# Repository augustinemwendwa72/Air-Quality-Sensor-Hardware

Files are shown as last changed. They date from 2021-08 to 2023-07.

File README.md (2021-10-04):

# sensors.AFRICA GSM AQ Kits Hardware

## Tools used

* Autodesk Eagle

* Fusion360

## sensors.AFRICA Stack

1. Firmware - https://github.com/CodeForAfrica/sensors.AFRICA-AQ-sensors-software
2. API - https://github.com/CodeForAfricaLabs/sensors.AFRICA-AQ-api
3. Map - https://github.com/CodeForAfrica/sensors.AFRICA-AQ-map-v2

## Documentation

The Documentation is under development.

## License

GNU General Public License v3.0

sensors.AFRICA is a citizen-science focused project by Code for Africa that seeks to address data gaps by providing low cost sensors, which people can use to measure and monitor the quality of the air, water, and environment in their communities. This web app seeks to be the public portal through which most users would discover and explore the data and intiative.

Copyright (C) 2021 Code for Africa

This program is free software: you can redistribute it and/or modify
it under the terms of the GNU General Public License as published by
the Free Software Foundation, either version 3 of the License, or
(at your option) any later version.

This program is distributed in the hope that it will be useful,
but WITHOUT ANY WARRANTY; without even the implied warranty of
MERCHANTABILITY or FITNESS FOR A PARTICULAR PURPOSE. See the
GNU General Public License for more details.

You should have received a copy of the GNU General Public License
along with this program. If not, see <https://www.gnu.org/licenses/>

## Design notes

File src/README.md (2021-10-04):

# sensors.AFRICA / GSM AQ sensors hardware

This folder contains the Eagle design files for the sensors.AFRICA GSM boards.

### Folders

* **AQ_sensor** The Printed Circuit Board of the AQ kit

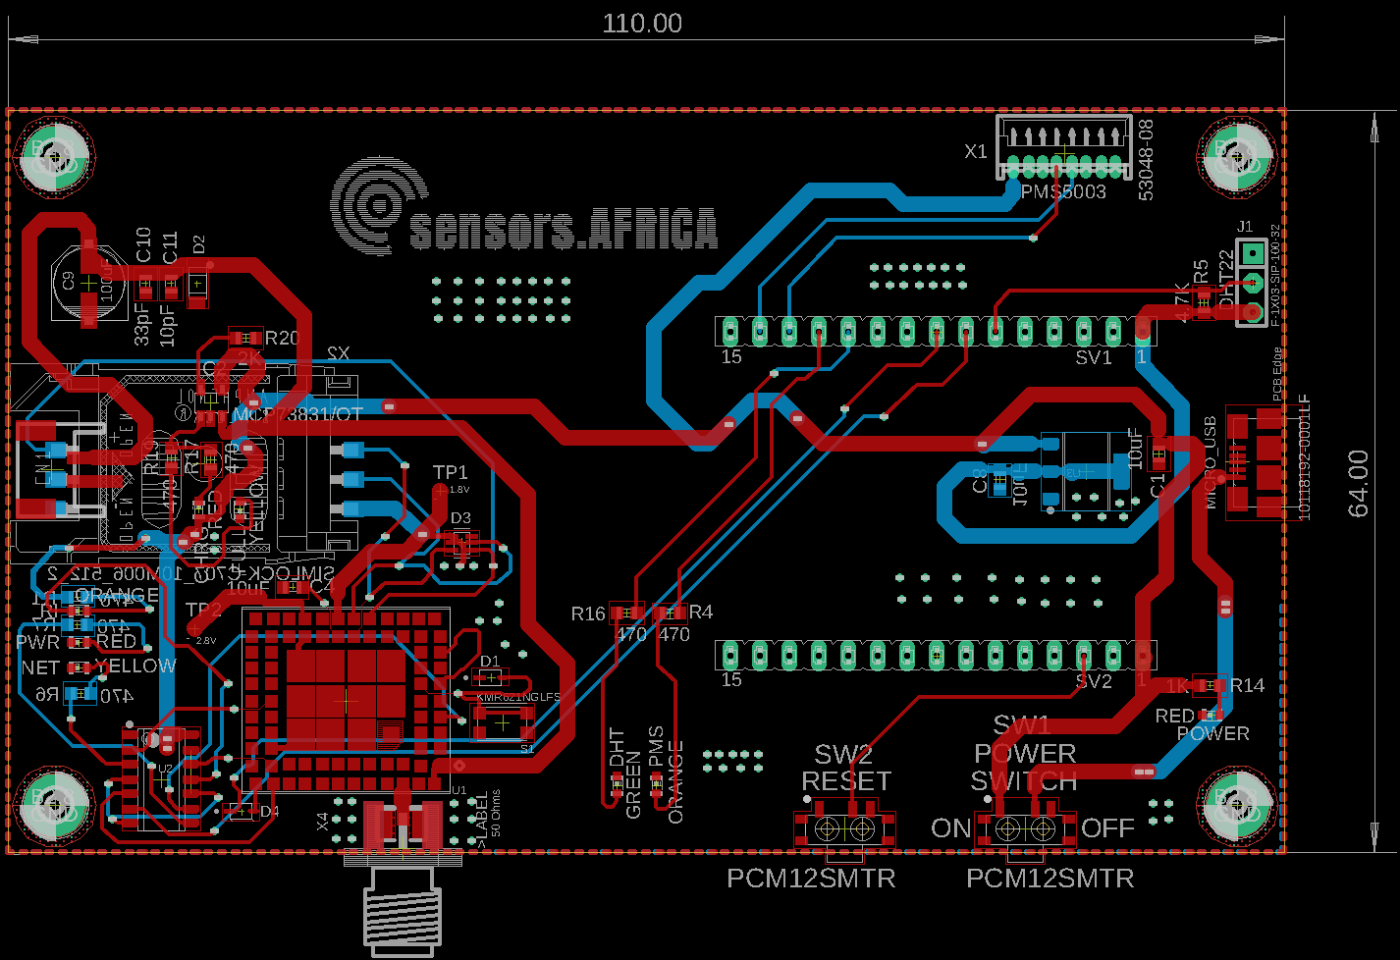
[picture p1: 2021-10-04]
src/AQ_sensors_GSM_brd.png

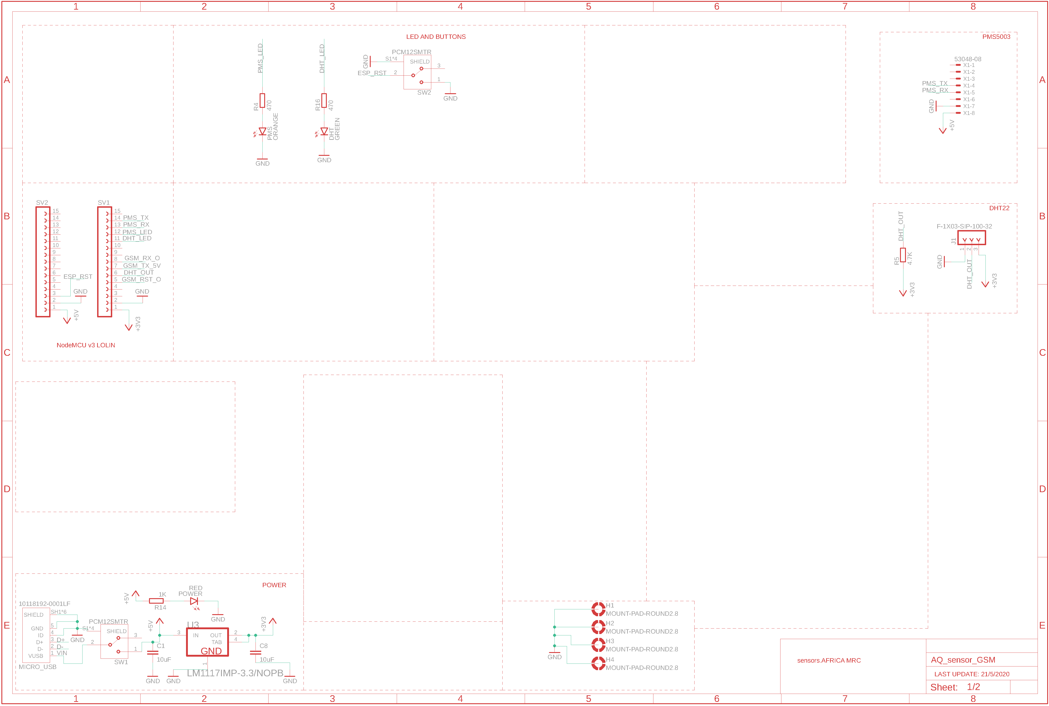
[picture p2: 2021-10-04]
src/AQ_sensors_GSM_sch.png

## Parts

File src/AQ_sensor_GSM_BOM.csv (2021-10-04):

Part | Value | Device | Package | Description | AVAILABILITY | BITS | CENTROID_NOT_SPECIFIED | CIIVA_IDS | CODE__IPC | CODE__JEDEC | CODE__JEITA | COMPONENT_LINK_1_DESCRIPTION | COMPONENT_LINK_1_URL | COMPONENT_LINK_3_DESCRIPTION | COMPONENT_LINK_3_URL | COMP_TYPE | DATASHEET | DATASHEET_VERSION | DESCRIPTION | DIGIKEY_DESCRIPTION | DIGIKEY_PART_NUMBER | FOOTPRINT_VARIANT_NAME_0 | FOOTPRINT_VARIANT_NAME_1 | FOOTPRINT_VARIANT_NAME_2 | F__NOM_VOLTAGEMAXMHZ | HIGH__RELIABILITY | ICC__NOM_VOLTAGEMAXMA | IMPORTED | IMPORTED_FROM | IMPORT_TS | INPUT_TYPE | IPC_LAND_PATTERN_NAME | JUNCTION_CAPACITANCE | LEAD_FREE | MANUFACTURER_PRODUCT_PAGE | MF | MFG_PACKAGE_IDENT | MFG_PACKAGE_IDENT_REV | MOUNTING_TECHNOLOGY | MOUSER_DESCRIPTION | MOUSER_PART_NUMBER | MP | MPN | OC_FARNELL | OC_NEWARK | OPERATING_TEMPERATURE_RANGEC | OUTPUT_TYPE | PACKAGE | PACKAGE_DESCRIPTION | PACKAGE_TOP_MARKING | PACKAGE_VERSION | PACKING | PIN_0_0_0_OUTSIDE_EDGE | PIN_0_1_0_OUTSIDE_EDGE | PIN_0_2_0_OUTSIDE_EDGE | PIN_0_3_2_OUTSIDE_EDGE | PIN_COUNT | POPULARITY | POWER_WISE
C1 | 10uF | C-EUC0603 | C0603 | CAPACITOR, European symbol |  |  |  |  |  |  |  |  |  |  |  |  |  |  |  |  |  |  |  |  |  |  |  |  |  |  |  |  |  |  |  |  |  |  |  |  |  |  |  |  |  |  |  |  |  |  |  |  |  |  |  |  |  | 73
C4 | 10uF | C-EUC0603 | C0603 | CAPACITOR, European symbol |  |  |  |  |  |  |  |  |  |  |  |  |  |  |  |  |  |  |  |  |  |  |  |  |  |  |  |  |  |  |  |  |  |  |  |  |  |  |  |  |  |  |  |  |  |  |  |  |  |  |  |  |  | 73
C8 | 10uF | C-EUC0603 | C0603 | CAPACITOR, European symbol |  |  |  |  |  |  |  |  |  |  |  |  |  |  |  |  |  |  |  |  |  |  |  |  |  |  |  |  |  |  |  |  |  |  |  |  |  |  |  |  |  |  |  |  |  |  |  |  |  |  |  |  |  | 73
C9 | 100uF | CPOL-EUD | PANASONIC_D | POLARIZED CAPACITOR, European symbol |  |  |  |  |  |  |  |  |  |  |  |  |  |  |  |  |  |  |  |  |  |  |  |  |  |  |  |  |  |  |  |  |  |  |  |  |  |  |  |  |  |  |  |  |  |  |  |  |  |  |  |  |  | 16
C10 | 33pF | C-EUC0603 | C0603 | CAPACITOR, European symbol |  |  |  |  |  |  |  |  |  |  |  |  |  |  |  |  |  |  |  |  |  |  |  |  |  |  |  |  |  |  |  |  |  |  |  |  |  |  |  |  |  |  |  |  |  |  |  |  |  |  |  |  |  | 73
C11 | 10pF | C-EUC0603 | C0603 | CAPACITOR, European symbol |  |  |  |  |  |  |  |  |  |  |  |  |  |  |  |  |  |  |  |  |  |  |  |  |  |  |  |  |  |  |  |  |  |  |  |  |  |  |  |  |  |  |  |  |  |  |  |  |  |  |  |  |  | 73
CHRG | RED | LEDCHIP-LED0603 | CHIP-LED0603 | LED |  |  |  |  |  |  |  |  |  |  |  |  |  |  |  |  |  |  |  |  |  |  |  |  |  |  |  |  |  |  |  |  |  |  |  |  |  |  |  |  |  |  |  |  |  |  |  |  |  |  |  |  |  | 26
CN1 |  | JST_2PIN-SMT-RA | JST-PH-2-SMT-RA | JST 2-Pin Connectors of various flavors
D1 | ON_SEMI_1N4148WSON_SEMI_1N4148WS_0_0 | ON_SEMI_1N4148WSON_SEMI_1N4148WS_0_0 | ON_SEMI_1N4148WS_0 | Small Signal Diodes |  |  | No |  |  |  |  |  |  |  |  |  | https://www.fairchildsemi.com/datasheets/1N/1N4148WS.pdf |  |  | DIODE GEN PURP 75V 150MA SOD323F | 1N4148WSFSCT-ND |  |  |  |  |  |  |  |  |  |  | SOD250125X70-2 |  | yes |  | ON Semi | CASE 477AB |  |  | Diodes - General Purpose, Power, Switching Small Signal Diode | 512-1N4148WS |  | 1N4148WS |  |  |  |  | SOD-323FL
D2 | ON_SEMICONDUCTOR_MMSZ5231BT1GON_SEMICONDUCTOR_MMSZ5231BT1G_0_0 | ON_SEMICONDUCTOR_MMSZ5231BT1GON_SEMICONDUCTOR_MMSZ5231BT1G_0_0 | ON_SEMICONDUCTOR_MMSZ5231BT1G_0 | ONSC-K1A2-2 |  |  |  | 804101 |  |  |  | Manufacturer URL | http://www.onsemi.com/ | Package Specification | http://www.onsemi.com/pub_link/Collateral/425-04.PDF |  | http://www.onsemi.com/pub_link/Collateral/MMSZ5221BT1-D.PDF | Rev. 12 |  |  |  | Manufacturer Recommended |  |  |  |  |  | yes | vault | 1521844429 |  |  |  |  |  | On Semiconductor |  |  | Surface Mount |  |  |  | MMSZ5231BT1G |  |  |  |  | SOD-123-2-425-04 | 2-Pin SOD, Body 1.6 x 2.69 mm |  | Rev. G, 10/2009 | Tape and Reel
D3 | SEMTECH_SMF05CSEMTECH_SMF05C_0_0 | SEMTECH_SMF05CSEMTECH_SMF05C_0_0 | SEMTECH_SMF05C_0 | TVS Diode Array |  |  | No |  |  |  |  |  |  |  |  |  | http://www.semtech.com/images/datasheet/smf05c.pdf |  |  | DIODE TVS DIODE 5VWM 12.5VC SC70-6 | SMF05CCT-ND |  |  |  |  |  |  |  |  |  |  |  | 130pF max | yes | http://www.semtech.com/apps/product.php?pn=SMF05C | Semtech | SC70-6L |  |  |  | 947-SMF05C.TCT |  | SMF05C |  |  |  |  | SC-70-6
D4 | ON_SEMI_1N4148WSON_SEMI_1N4148WS_0_0 | ON_SEMI_1N4148WSON_SEMI_1N4148WS_0_0 | ON_SEMI_1N4148WS_0 | Small Signal Diodes |  |  | No |  |  |  |  |  |  |  |  |  | https://www.fairchildsemi.com/datasheets/1N/1N4148WS.pdf |  |  | DIODE GEN PURP 75V 150MA SOD323F | 1N4148WSFSCT-ND |  |  |  |  |  |  |  |  |  |  | SOD250125X70-2 |  | yes |  | ON Semi | CASE 477AB |  |  | Diodes - General Purpose, Power, Switching Small Signal Diode | 512-1N4148WS |  | 1N4148WS |  |  |  |  | SOD-323FL
DHT | GREEN | LEDCHIP-LED0603 | CHIP-LED0603 | LED |  |  |  |  |  |  |  |  |  |  |  |  |  |  |  |  |  |  |  |  |  |  |  |  |  |  |  |  |  |  |  |  |  |  |  |  |  |  |  |  |  |  |  |  |  |  |  |  |  |  |  |  |  | 26
FULL | YELLOW | LEDCHIP-LED0603 | CHIP-LED0603 | LED |  |  |  |  |  |  |  |  |  |  |  |  |  |  |  |  |  |  |  |  |  |  |  |  |  |  |  |  |  |  |  |  |  |  |  |  |  |  |  |  |  |  |  |  |  |  |  |  |  |  |  |  |  | 26
H1 | MOUNT-PAD-ROUND2.8 | MOUNT-PAD-ROUND2.8 | 2,8-PAD | MOUNTING PAD, round |  |  |  |  |  |  |  |  |  |  |  |  |  |  |  |  |  |  |  |  |  |  |  |  |  |  |  |  |  |  |  |  |  |  |  |  |  |  |  |  |  |  |  |  |  |  |  |  |  |  |  |  |  | 6
H2 | MOUNT-PAD-ROUND2.8 | MOUNT-PAD-ROUND2.8 | 2,8-PAD | MOUNTING PAD, round |  |  |  |  |  |  |  |  |  |  |  |  |  |  |  |  |  |  |  |  |  |  |  |  |  |  |  |  |  |  |  |  |  |  |  |  |  |  |  |  |  |  |  |  |  |  |  |  |  |  |  |  |  | 6
H3 | MOUNT-PAD-ROUND2.8 | MOUNT-PAD-ROUND2.8 | 2,8-PAD | MOUNTING PAD, round |  |  |  |  |  |  |  |  |  |  |  |  |  |  |  |  |  |  |  |  |  |  |  |  |  |  |  |  |  |  |  |  |  |  |  |  |  |  |  |  |  |  |  |  |  |  |  |  |  |  |  |  |  | 6
H4 | MOUNT-PAD-ROUND2.8 | MOUNT-PAD-ROUND2.8 | 2,8-PAD | MOUNTING PAD, round |  |  |  |  |  |  |  |  |  |  |  |  |  |  |  |  |  |  |  |  |  |  |  |  |  |  |  |  |  |  |  |  |  |  |  |  |  |  |  |  |  |  |  |  |  |  |  |  |  |  |  |  |  | 6
IC2 | MCP73831/OT | MCP73831/OT | SOT23-5L | MCP73831/2
J1 | F-1X03-SIP-100-32 | F-1X03-SIP-100-32 | SIP-100-03-32 | FEMALE HEADER
MICRO_USB | 10118192-0001LF | 10118192-0001LF | AMPHENOL_10118192-0001LF | Single Port 5 Contact Horizontal Right Angle Shielded Micro B USB 2.0 Connector | Unavailable |  |  |  |  |  |  |  |  |  |  |  |  |  | USB - micro B USB 2.0 Receptacle Connector 5 Position Surface Mount, Right Angle |  |  |  |  |  |  |  |  |  |  |  |  |  |  |  |  | Amphenol ICC |  |  |  |  |  | 10118192-0001LF |  |  |  |  |  | None
NET | YELLOW | LEDCHIP-LED0603 | CHIP-LED0603 | LED |  |  |  |  |  |  |  |  |  |  |  |  |  |  |  |  |  |  |  |  |  |  |  |  |  |  |  |  |  |  |  |  |  |  |  |  |  |  |  |  |  |  |  |  |  |  |  |  |  |  |  |  |  | 26
PMS | ORANGE | LEDCHIP-LED0603 | CHIP-LED0603 | LED |  |  |  |  |  |  |  |  |  |  |  |  |  |  |  |  |  |  |  |  |  |  |  |  |  |  |  |  |  |  |  |  |  |  |  |  |  |  |  |  |  |  |  |  |  |  |  |  |  |  |  |  |  | 26
POWER | RED | LEDCHIP-LED0603 | CHIP-LED0603 | LED |  |  |  |  |  |  |  |  |  |  |  |  |  |  |  |  |  |  |  |  |  |  |  |  |  |  |  |  |  |  |  |  |  |  |  |  |  |  |  |  |  |  |  |  |  |  |  |  |  |  |  |  |  | 26
PWR | RED | LEDCHIP-LED0603 | CHIP-LED0603 | LED |  |  |  |  |  |  |  |  |  |  |  |  |  |  |  |  |  |  |  |  |  |  |  |  |  |  |  |  |  |  |  |  |  |  |  |  |  |  |  |  |  |  |  |  |  |  |  |  |  |  |  |  |  | 26
R1 | 470 | R-EU_R0603 | R0603 | RESISTOR, European symbol |  |  |  |  |  |  |  |  |  |  |  |  |  |  |  |  |  |  |  |  |  |  |  |  |  |  |  |  |  |  |  |  |  |  |  |  |  |  |  |  |  |  |  |  |  |  |  |  |  |  |  |  |  | 70
R4 | 470 | R-EU_R0603 | R0603 | RESISTOR, European symbol |  |  |  |  |  |  |  |  |  |  |  |  |  |  |  |  |  |  |  |  |  |  |  |  |  |  |  |  |  |  |  |  |  |  |  |  |  |  |  |  |  |  |  |  |  |  |  |  |  |  |  |  |  | 70
R5 | 4.7K | R-EU_R0603 | R0603 | RESISTOR, European symbol |  |  |  |  |  |  |  |  |  |  |  |  |  |  |  |  |  |  |  |  |  |  |  |  |  |  |  |  |  |  |  |  |  |  |  |  |  |  |  |  |  |  |  |  |  |  |  |  |  |  |  |  |  | 70
R6 | 470 | R-EU_R0603 | R0603 | RESISTOR, European symbol |  |  |  |  |  |  |  |  |  |  |  |  |  |  |  |  |  |  |  |  |  |  |  |  |  |  |  |  |  |  |  |  |  |  |  |  |  |  |  |  |  |  |  |  |  |  |  |  |  |  |  |  |  | 70
R7 | 470 | R-EU_R0603 | R0603 | RESISTOR, European symbol |  |  |  |  |  |  |  |  |  |  |  |  |  |  |  |  |  |  |  |  |  |  |  |  |  |  |  |  |  |  |  |  |  |  |  |  |  |  |  |  |  |  |  |  |  |  |  |  |  |  |  |  |  | 70
R14 | 1K | R-EU_R0603 | R0603 | RESISTOR, European symbol |  |  |  |  |  |  |  |  |  |  |  |  |  |  |  |  |  |  |  |  |  |  |  |  |  |  |  |  |  |  |  |  |  |  |  |  |  |  |  |  |  |  |  |  |  |  |  |  |  |  |  |  |  | 70
R16 | 470 | R-EU_R0603 | R0603 | RESISTOR, European symbol |  |  |  |  |  |  |  |  |  |  |  |  |  |  |  |  |  |  |  |  |  |  |  |  |  |  |  |  |  |  |  |  |  |  |  |  |  |  |  |  |  |  |  |  |  |  |  |  |  |  |  |  |  | 70
R17 | 470 | R-EU_R0603 | R0603 | RESISTOR, European symbol |  |  |  |  |  |  |  |  |  |  |  |  |  |  |  |  |  |  |  |  |  |  |  |  |  |  |  |  |  |  |  |  |  |  |  |  |  |  |  |  |  |  |  |  |  |  |  |  |  |  |  |  |  | 70
R19 | 470 | R-EU_R0603 | R0603 | RESISTOR, European symbol |  |  |  |  |  |  |  |  |  |  |  |  |  |  |  |  |  |  |  |  |  |  |  |  |  |  |  |  |  |  |  |  |  |  |  |  |  |  |  |  |  |  |  |  |  |  |  |  |  |  |  |  |  | 70
R20 | 2K | R-EU_R0603 | R0603 | RESISTOR, European symbol |  |  |  |  |  |  |  |  |  |  |  |  |  |  |  |  |  |  |  |  |  |  |  |  |  |  |  |  |  |  |  |  |  |  |  |  |  |  |  |  |  |  |  |  |  |  |  |  |  |  |  |  |  | 70
RI | ORANGE | LEDCHIP-LED0603 | CHIP-LED0603 | LED |  |  |  |  |  |  |  |  |  |  |  |  |  |  |  |  |  |  |  |  |  |  |  |  |  |  |  |  |  |  |  |  |  |  |  |  |  |  |  |  |  |  |  |  |  |  |  |  |  |  |  |  |  | 26
S1 | KMR621NGLFS | KMR621NGLFS | SW_KMR621NGLFS | Tactile Switches 50mA 32VDC 1.9mmH 2N IP67 | Unavailable |  |  |  |  |  |  |  |  |  |  |  |  |  | Tactile Switch SPST-NO Top Actuated Surface Mount |  |  |  |  |  |  |  |  |  |  |  |  |  |  |  |  | C&K |  |  |  |  |  | KMR621NG LFS |  |  |  |  |  | None
SV1 |  | FE15-1 | FE15 | FEMALE HEADER |  |  |  |  |  |  |  |  |  |  |  |  |  |  |  |  |  |  |  |  |  |  |  |  |  |  |  |  |  |  |  |  |  |  |  |  |  |  |  | unknown | unknown |  |  |  |  |  |  |  |  |  |  |  |  | 2
SV2 |  | FE15-1 | FE15 | FEMALE HEADER |  |  |  |  |  |  |  |  |  |  |  |  |  |  |  |  |  |  |  |  |  |  |  |  |  |  |  |  |  |  |  |  |  |  |  |  |  |  |  | unknown | unknown |  |  |  |  |  |  |  |  |  |  |  |  | 2
SW1 | PCM12SMTR | PCM12SMTR | SW_PCM12SMTR | Switch Slide ON ON SPDT Side Slide 0.3A 6VDC 10000Cycles Gull Wing SMD T/R | Unavailable |  |  |  |  |  |  |  |  |  |  |  |  |  | Slide Switch SPDT Surface Mount, Right Angle |  |  |  |  |  |  |  |  |  |  |  |  |  |  |  |  | C&K |  |  |  |  |  | PCM12SMTR |  |  |  |  |  | DO-201 C&amp | K Components
SW2 | PCM12SMTR | PCM12SMTR | SW_PCM12SMTR | Switch Slide ON ON SPDT Side Slide 0.3A 6VDC 10000Cycles Gull Wing SMD T/R | Unavailable |  |  |  |  |  |  |  |  |  |  |  |  |  | Slide Switch SPDT Surface Mount, Right Angle |  |  |  |  |  |  |  |  |  |  |  |  |  |  |  |  | C&K |  |  |  |  |  | PCM12SMTR |  |  |  |  |  | DO-201 C&amp | K Components
TP1 | TPB1,27 | TPB1,27 | B1,27 | Test pad |  |  |  |  |  |  |  |  |  |  |  |  |  |  |  |  |  |  |  |  |  |  |  |  |  |  |  |  |  |  |  |  |  |  |  |  |  |  |  |  |  |  |  |  |  |  |  |  |  |  |  |  |  | 19
TP2 | TPB1,27 | TPB1,27 | B1,27 | Test pad |  |  |  |  |  |  |  |  |  |  |  |  |  |  |  |  |  |  |  |  |  |  |  |  |  |  |  |  |  |  |  |  |  |  |  |  |  |  |  |  |  |  |  |  |  |  |  |  |  |  |  |  |  | 19
U1 |  | GSM_SIM800L | SIM800L | SIM800K Quad-Band GSM/GPRS Module
U2 | TEXAS_INSTRUMENTS_SN74HC125TEXAS_INSTRUMENTS_SN74HC125_0_0 | TEXAS_INSTRUMENTS_SN74HC125TEXAS_INSTRUMENTS_SN74HC125_0_0 | TEXAS_INSTRUMENTS_SN74HC125_0 | TI-SN74HC125-D0014A-14 |  | 4 |  | 1347642 |  | MS-012 |  |  |  |  |  |  |  | SCLS104D |  |  |  | Level C | Level B | Level A | 28 |  | 0.16 | yes | vault | 1521847871 | CMOS |  |  |  |  | Texas Instruments |  |  |  |  |  |  | SN74HC125 |  |  | -40 to 85 | CMOS | D0014A |  |  | http://www.ti.com/lit/ml/mpds177g/mpds177g.pdf |  | dot | dot | dot | dot
U3 | TEXAS_INSTRUMENTS_LM1117IMP-3.3-NOPBTEXAS_INSTRUMENTS_LM1117IMP-3.3-NOPB_0_0 | TEXAS_INSTRUMENTS_LM1117IMP-3.3-NOPBTEXAS_INSTRUMENTS_LM1117IMP-3.3-NOPB_0_0 | TEXAS_INSTRUMENTS_LM1117IMP-3.3-NOPB_0 | PM-REG-LM1086-SOT4 |  |  |  | 19361124 | SOT223-4 | TO-261-AA |  | Datasheet URL | http://www.ti.com/general/docs/lit/getliterature.tsp?genericPartNumber=LM1117-N&fileType=pdf |  |  | LDO IC |  |  |  |  |  | Level C | Level B | Level A |  | Y |  | yes | vault | 1521845365 |  |  |  |  |  | Texas Instruments |  |  |  |  |  |  | LM1117IMP-3.3/NOPB |  |  |  |  | DCY0004A | Molded SOT-223, 6.50 x 3.56 x 1.6mm Body, 4 Lead, 2.3mm Pitch | XYTT*N05B |  |  |  |  |  |  | 4 |  | N
X1 | 53048-08 | 53048-08 | 53048-08 | CONNECTOR |  |  |  |  |  |  |  |  |  |  |  |  |  |  |  |  |  |  |  |  |  |  |  |  |  |  |  |  |  |  |  | WALDOM/MOLEX |  |  |  |  |  |  | 53048-0810 | 9733094 | 38C9913 |  |  |  |  |  |  |  |  |  |  |  |  | 0
X2 | SIMLOCK-C707_10M006_512_2 | SIMLOCK-C707_10M006_512_2 | C707_10M006_512_2 | C707A SIMLOCK® 2.5 mm with wide solder tails |  |  |  |  |  |  |  |  |  |  |  |  |  |  |  |  |  |  |  |  |  |  |  |  |  |  |  |  |  |  |  |  |  |  |  |  |  |  |  | unknown | unknown |  |  |  |  |  |  |  |  |  |  |  |  | 1
X4 | 50 Ohms | SMACONNECTOR_EDGE_UFL | SMA_EDGELAUNCH_UFL | SMA Connector
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

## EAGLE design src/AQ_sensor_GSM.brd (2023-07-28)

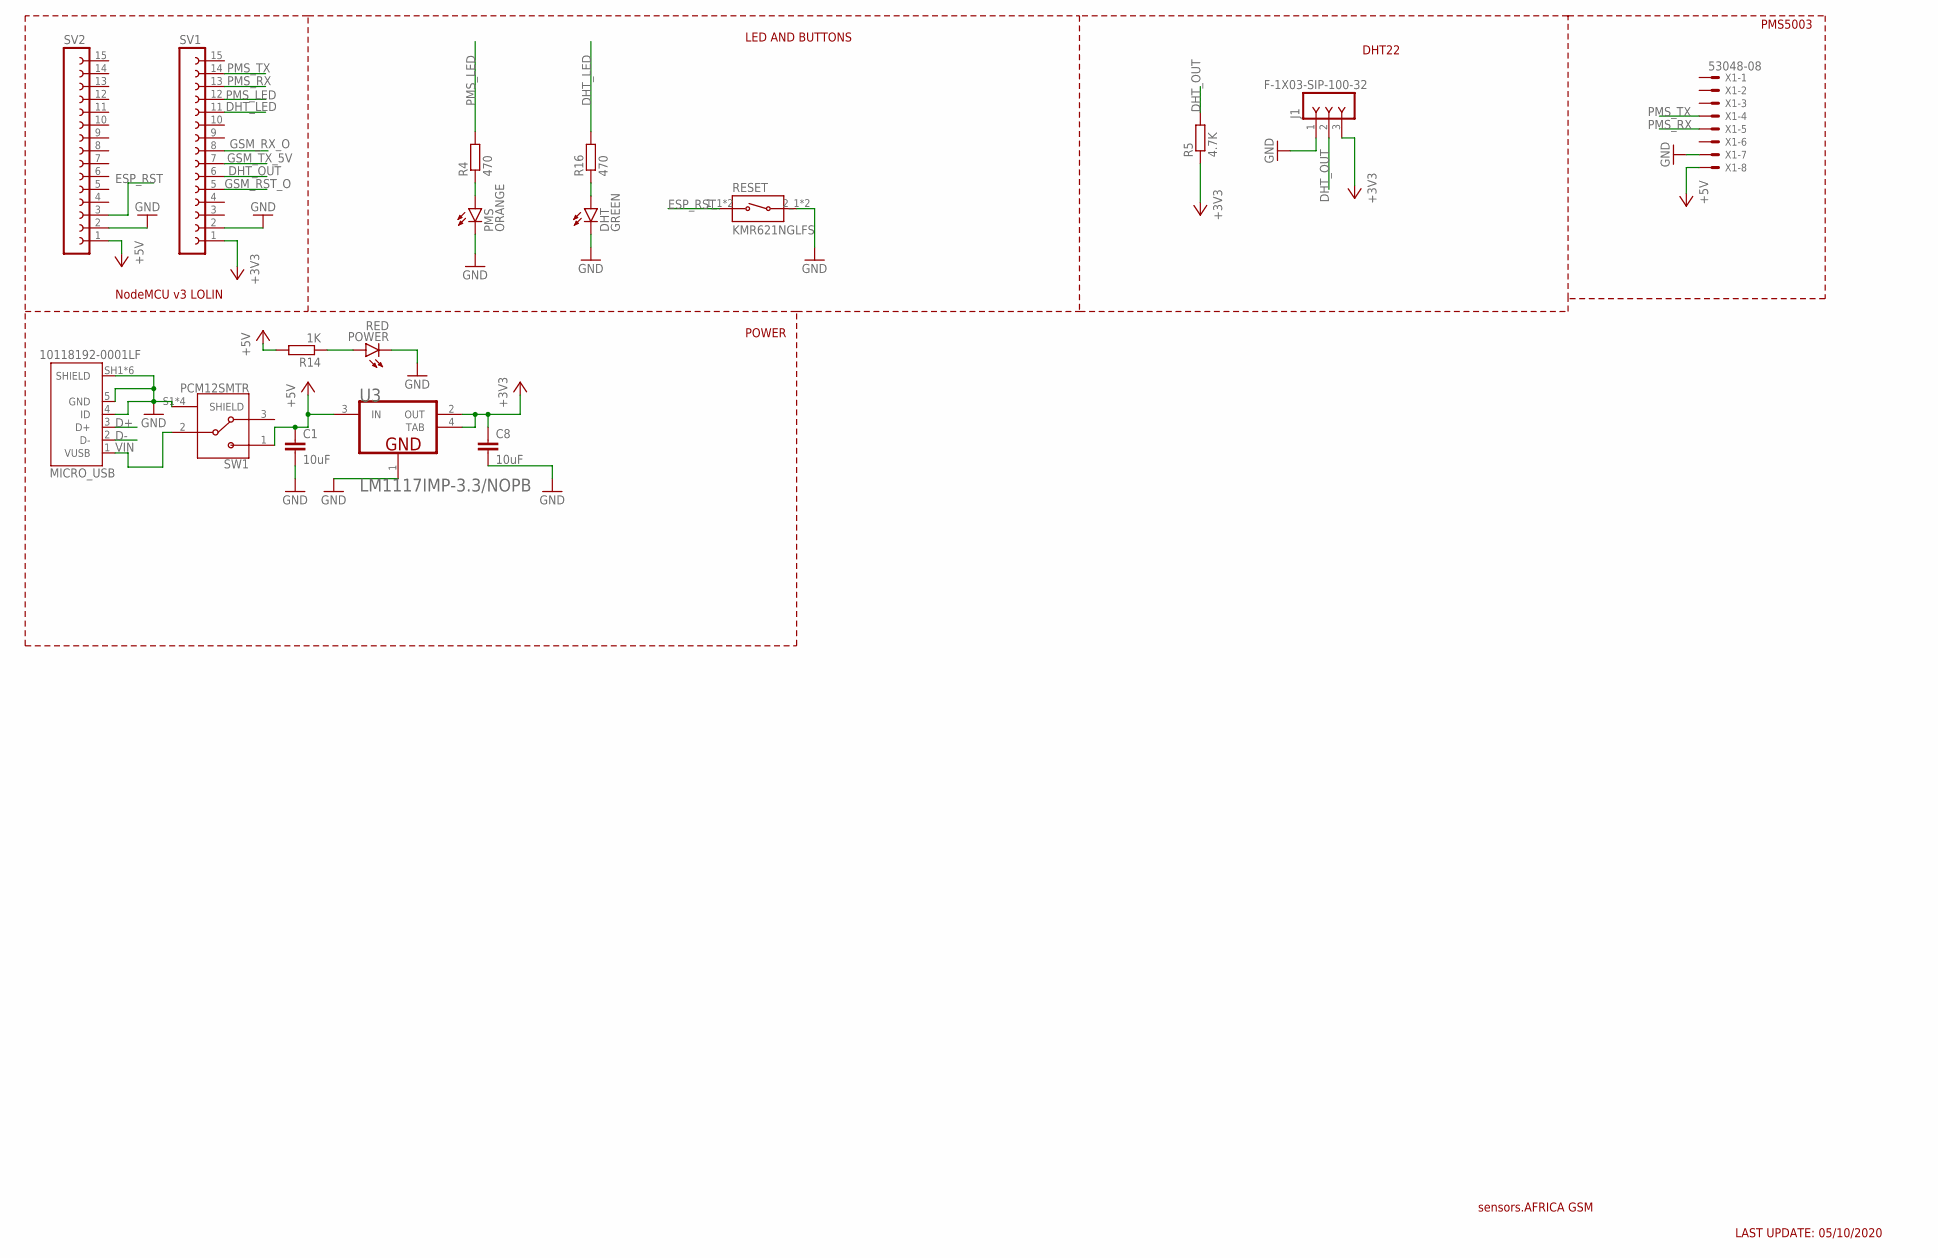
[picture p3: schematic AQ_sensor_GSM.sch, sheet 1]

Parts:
C1, C8: 10uF; C0603
DHT: GREEN; CHIP-LED0603
J1: F-1X03-SIP-100-32; SIP-100-03-32
MICRO_USB: 10118192-0001LF; AMPHENOL_10118192-0001LF
PMS: ORANGE; CHIP-LED0603
POWER: RED; CHIP-LED0603
R4, R16: 470; R0603
R5: 4.7K; R0603
R14: 1K; R0603
RESET: KMR621NGLFS; SW_KMR621NGLFS
SV1, SV2: FE15-1; FE15
SW1: PCM12SMTR; SW_PCM12SMTR
U3: TEXAS_INSTRUMENTS_LM1117IMP-3.3-NOPBTEXAS_INSTRUM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; TEXAS_INSTRUMENTS_LM1117IMP-3.3-NOPB_0
X1: 53048-08

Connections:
+3V3: C8.1, J1.3, R5.1, SV1.1, U3.2 (OUT), U3.4 (TAB)
+5V: C1.1, R14.2, SV2.1, SW1.1, U3.3 (IN), X1.8; also elsewhere on the board
D+: MICRO_USB.3 (D+)
D-: MICRO_USB.2 (D-)
DHT_LED: R16.2, SV1.11
DHT_OUT: J1.2, R5.2, SV1.6
ESP_RST: RESET.1_1 (1), RESET.1_2 (1), SV2.3
GND: C1.2, C8.2, DHT.C, J1.1, MICRO_USB.4 (ID), MICRO_USB.5 (GND), MICRO_USB.SH1 (SHIELD), MICRO_USB.SH2 (SHIELD), MICRO_USB.SH3 (SHIELD), MICRO_USB.SH4 (SHIELD), MICRO_USB.SH5 (SHIELD), MICRO_USB.SH6 (SHIELD), PMS.C, POWER.C, RESET.2_1 (2), RESET.2_2 (2), SV1.2, SV2.2, SW1.S1 (SHIELD), SW1.S2 (SHIELD), SW1.S3 (SHIELD), SW1.S4 (SHIELD), U3.1 (GND), X1.7; also elsewhere on the board
GSM_RST_O: SV1.5
GSM_RX_O: SV1.8; also elsewhere on the board
GSM_TX_5V: SV1.7; also elsewhere on the board
unnamed: PMS.A, R4.1
unnamed: POWER.A, R14.1
unnamed: DHT.A, R16.1
PMS_LED: R4.2, SV1.12
PMS_RX: SV1.13, X1.5
PMS_TX: SV1.14, X1.4
VIN: MICRO_USB.1 (VUSB), SW1.2

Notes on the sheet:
sensors.AFRICA GSM
LAST UPDATE: 05/10/2020
LED AND BUTTONS
PMS5003
DHT22
NodeMCU v3 LOLIN
POWER

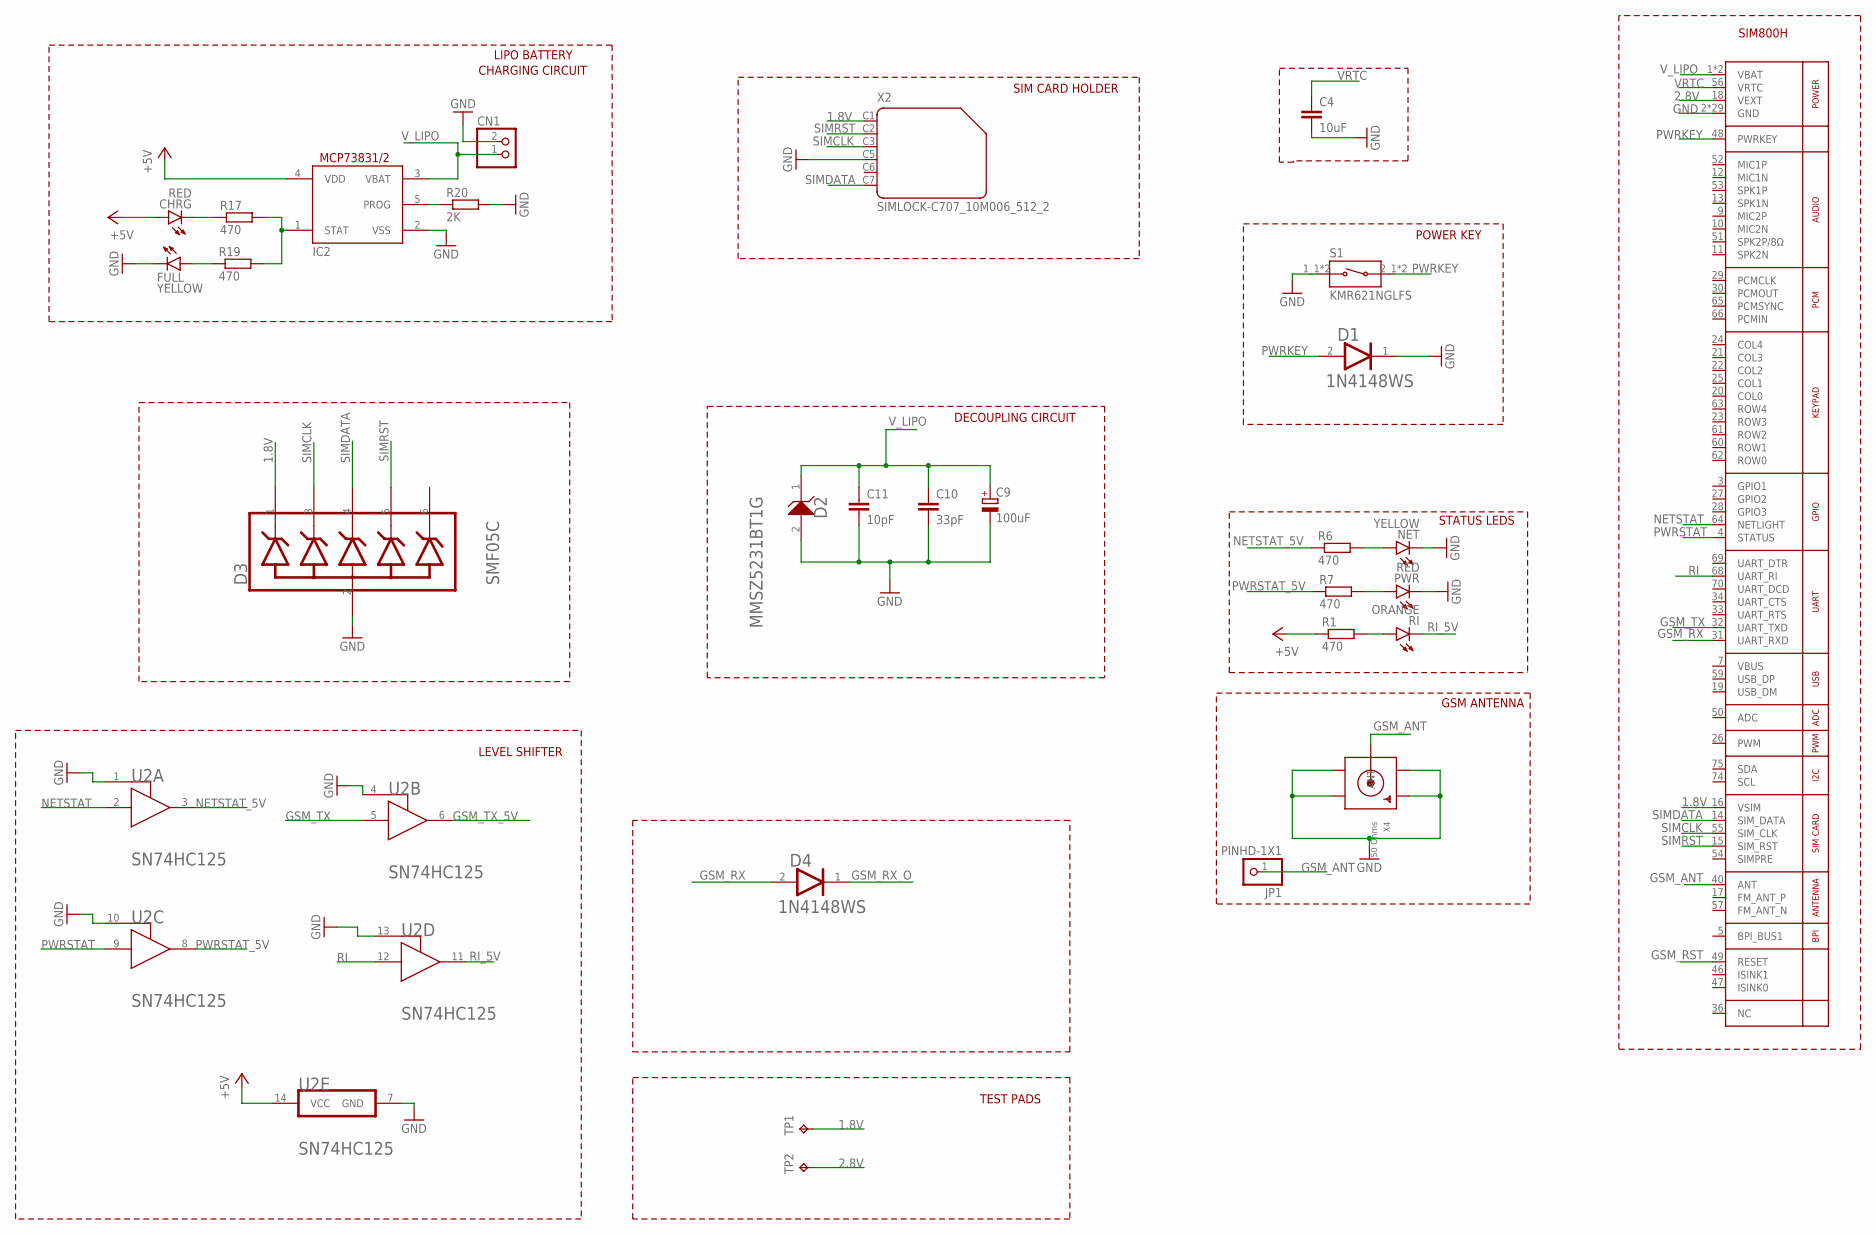
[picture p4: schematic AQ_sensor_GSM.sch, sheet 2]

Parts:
C4: 10uF; C0603
C9: 100uF; PANASONIC_D
C10: 33pF; C0603
C11: 10pF; C0603
CHRG: RED; CHIP-LED0603
CN1: JST_2PIN-SMT-RA; JST-PH-2-SMT-RA
D1, D4: ON_SEMI_1N4148WSON_SEMI_1N4148WS_0_0; ON_SEMI_1N4148WS_0
D2: ON_SEMICONDUCTOR_MMSZ5231BT1GON_SEMICONDUCTOR_MMS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; ON_SEMICONDUCTOR_MMSZ5231BT1G_0
D3: SEMTECH_SMF05CSEMTECH_SMF05C_0_0; SEMTECH_SMF05C_0
FULL: YELLOW; CHIP-LED0603
IC2: MCP73831/OT; SOT23-5L
JP1: PINHD-1X1; 1X01
NET: YELLOW; CHIP-LED0603
PWR: RED; CHIP-LED0603
R1, R6, R7, R17, R19: 470; R0603
R20: 2K; R0603
RI: ORANGE; CHIP-LED0603
S1: KMR621NGLFS; SW_KMR621NGLFS
TP1, TP2: TPB1,27; B1,27
U1: GSM_SIM800L; SIM800L
U2: TEXAS_INSTRUMENTS_SN74HC125TEXAS_INSTRUMENTS_SN74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; TEXAS_INSTRUMENTS_SN74HC125_0
X2: SIMLOCK-C707_10M006_512_2; C707_10M006_512_2
X4: 50 Ohms; SMA_EDGELAUNCH_UFL

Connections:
1.8V: D3.1 (1_CATHODE), TP1.TP, U1.16 (VSIM), X2.C1 (1)
2.8V: TP2.TP, U1.18 (VEXT)
+5V: CHRG.A, IC2.4 (VDD), R1.1, U2.14 (VCC); also elsewhere on the board
GND: C4.2, C9.-, C10.2, C11.2, CN1.2 (1), D1.1 (CATHODE), D2.2 (A), D3.2 (ANODE), FULL.C, IC2.2 (VSS), NET.C, PWR.C, R20.2, S1.1_1 (1), S1.1_2 (1), U1.2 (GND), U1.6 (GND), U1.8 (GND), U1.35 (GND), U1.37 (GND), U1.38 (GND), U1.39 (GND), U1.41 (GND), U1.43 (GND), U1.44 (GND), U1.45 (GND), U1.58 (GND), U1.67 (GND), U1.71 (GND), U1.72 (GND), U1.73 (GND), U1.76 (GND), U1.77 (GND), U1.78 (GND), U1.79 (GND), U1.80 (GND), U1.81 (GND), U1.82 (GND), U1.83 (GND), U1.84 (GND), U1.85 (GND), U1.86 (GND), U1.87 (GND), U1.88 (GND), U2.1 (1_!OE!), U2.4 (4_!OE!), U2.7 (GND), U2.10 (2_!OE!), U2.13 (3_!OE!), X2.C5 (4), X4.GND@1 (GND1), X4.GND@2 (GND2), X4.GND@3 (GND3), X4.GND@4 (GND4); also elsewhere on the board
GSM_ANT: JP1.1, U1.40 (ANT), X4.P (ANT)
GSM_RST: U1.49 (RESET)
GSM_RX: D4.2 (ANODE), U1.31 (UART_RXD)
GSM_RX_O: D4.1 (CATHODE); also elsewhere on the board
GSM_TX: U1.32 (UART_TXD), U2.5 (2A)
GSM_TX_5V: U2.6 (2Y); also elsewhere on the board
unnamed: CHRG.C, R17.1
unnamed: IC2.1 (STAT), R17.2, R19.2
unnamed: NET.A, R6.2
unnamed: PWR.A, R7.2
unnamed: FULL.A, R19.1
unnamed: IC2.5 (PROG), R20.1
unnamed: R1.2, RI.A
NETSTAT: U1.64 (NETLIGHT), U2.2 (1A)
NETSTAT_5V: R6.1, U2.3 (1Y)
PWRKEY: D1.2 (ANODE), S1.2_1 (2), S1.2_2 (2), U1.48 (PWRKEY)
PWRSTAT: U1.4 (STATUS), U2.9 (3A)
PWRSTAT_5V: R7.1, U2.8 (3Y)
RI: U1.68 (UART_RI), U2.12 (4A)
RI_5V: RI.C, U2.11 (4Y)
SIMCLK: D3.3 (2_CATHODE), U1.55 (SIM_CLK), X2.C3 (3)
SIMDATA: D3.4 (3_CATHODE), U1.14 (SIM_DATA), X2.C7 (6)
SIMRST: D3.5 (4_CATHODE), U1.15 (SIM_RST), X2.C2 (2)
VBUS: U1.7 (VBUS)
VRTC: C4.1, U1.56 (VRTC)
V_LIPO: C9.+, C10.1, C11.1, CN1.1 (2), D2.1 (K), IC2.3 (VBAT), U1.1 (VBAT), U1.42 (VBAT)

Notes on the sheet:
SIM800H
POWER KEY
STATUS LEDS
SIM CARD HOLDER
CHARGING CIRCUIT
LIPO BATTERY
GSM ANTENNA
TEST PADS
LEVEL SHIFTER
DECOUPLING CIRCUIT

Board: 2 copper layers, 46 parts (0 on the bottom side), 39 nets, no tracks yet.

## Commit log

2021-08-24 Added Board design and schematic
    [AQ_sensor_GSM.brd, AQ_sensor_GSM.sch]
2021-08-27 Optimized power planes
    [AQ_sensor_GSM.brd]
2021-08-27 Added copper fills
    [AQ_sensor_GSM.brd]
2021-09-28 Added stitching vias
    [AQ_sensor_GSM.brd, AQ_sensor_GSM.sch]
2021-09-28 Added manufacturing files
    [AQ_sensor_GSM.brd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]
2021-09-28 Added Bill of Materials
    [AQ_sensor_GSM_BOM.csv]
2021-09-28 Added board layout image
2021-09-28 Added board schematic image
2021-10-04 created src folder
    [AQ_sensor_GSM.brd, AQ_sensor_GSM.sch, AQ_sensor_GSM_BOM.csv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]
2021-10-04 changed board type to GSM
2021-10-12 sorted DRC
    [AQ_sensor_GSM.brd, AQ_sensor_GSM.sch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]
2021-10-18 Organized schematic
    [AQ_sensor_GSM.brd, AQ_sensor_GSM.sch]
2023-07-28 Feature: Change components' positions.
    1. Rotate NodeMCU 90 degrees anti-clockwise. 2. Add onboard GSM Antenna. 3. Move Simcard Holder to top Layer. 4. Change Reset button to push button. 5. Rearrange Charging Circuitry layout to minimise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
    [AQ_sensor_GSM.brd, AQ_sensor_GSM.sch]
